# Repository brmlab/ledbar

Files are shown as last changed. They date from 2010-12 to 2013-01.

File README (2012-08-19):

eagle: PCB design
arduino: Semi-generic TLC59116 library and ledbar Arduino firmware
host: C frontend
host_python: Python frontend

Both the C frontend and the Python frontend have their pros and cons.
We still use both and it's unclear which one will prevail. Try them
and use the one you like better.

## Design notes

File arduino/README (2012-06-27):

autonomous.pde: This is autonomous LED controller that implements several
simple color cycling algorithms directly on Ardiuno - no host controller
is required. All LEDs have the same color. Useful for testing.

controlled.pde: Listens to a byte stream on serial. The byte stream should
contain one R,G,B tribyte per LED, sent repeatedly.

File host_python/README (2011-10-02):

INTRODUCTION:

The scripts in this directory try to work according to the KISS principle. It 
contains a script which redirects its stdin to serial device 
(send_to_serial.py), one that simulates the ledbar and sends the data unaltered 
from its stdin to its stdout, a module that helps programmers to program 
various graphical effects and some example effect generators using this module.

EXAMPLES:

./rainbow.py | ./demo.py >/dev/null
    - only simulate the rainbow effect, do not send it anywhere

./rainbow.py | ./send_to_serial.py
    - only send the data to the serial device, do not show the simulation

./rainbow.py | ./demo.py | ./send_to_serial.py
    - combine both options, show a simulation and send the data to the serial
      device

DEPENDENCIES:

demo.py requires PyGame, Python wrapper around SDL
send_to_serial.py requires PySerial, Python library for work with serial ports
equalizer.py requires PyAudio (wrapper around PortAudio) and a microphone

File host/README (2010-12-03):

* http://brmlab.cz/project/ledbar

* control with Q, W

* quit with escape or close the window

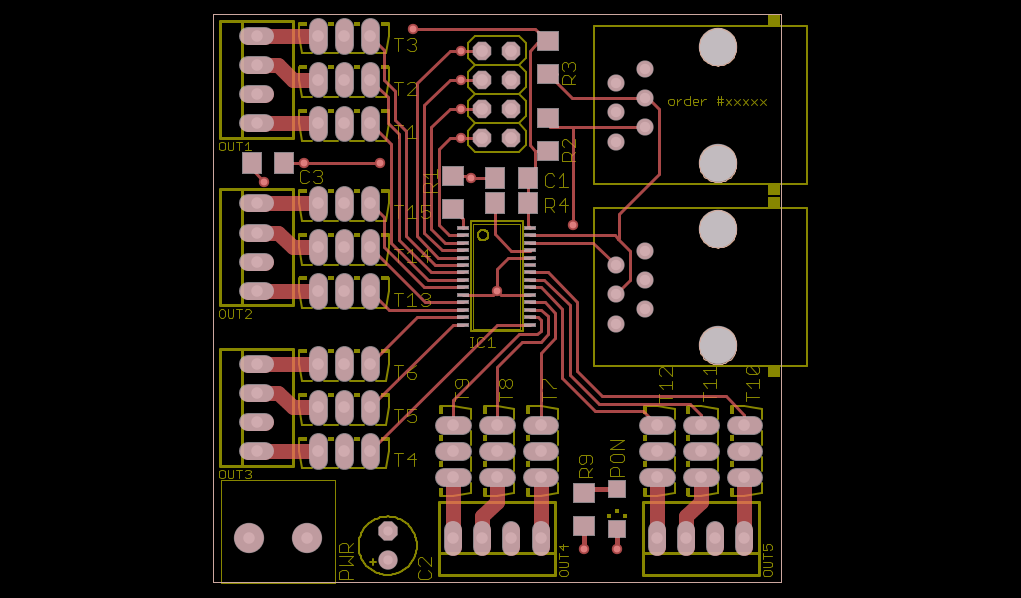
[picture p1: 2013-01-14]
eagle/ledbar/top.png

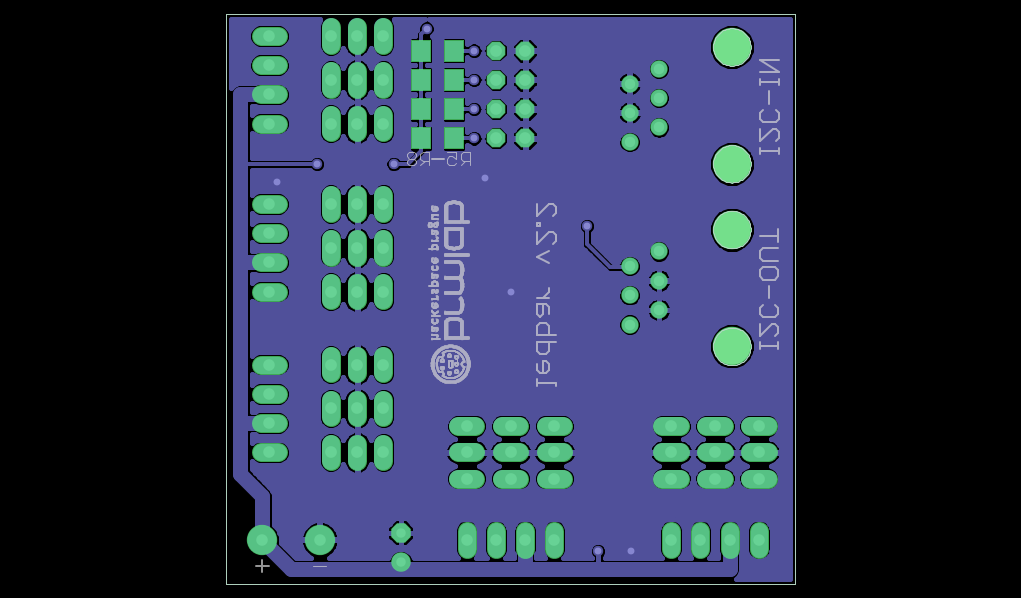
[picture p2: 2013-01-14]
eagle/ledbar/bottom.png

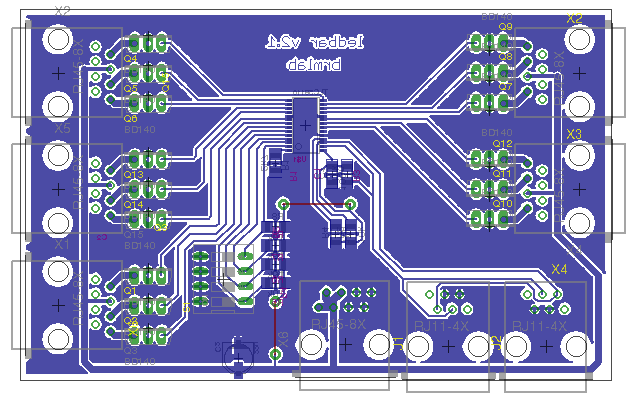
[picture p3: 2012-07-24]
eagle/ledbar/board_v2.1.png

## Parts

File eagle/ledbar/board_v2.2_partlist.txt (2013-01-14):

Partlist

Exported from board_v2.brd at 1/10/13 10:36 PM

EAGLE Version 6.3.0 Copyright (c) 1988-2012 CadSoft

Assembly variant: 

Part     Value          Package        Library             Position (mm)         Orientation

C1       100n           C1206          resistor            (26.035 35.2425)      R180
C2       22u            E2,5-5         resistor            (15.24 3.175)         R90
C3       1u             C1206          resistor            (4.7625 36.5125)      R180
I2C-IN   RJ11-4X        RJ11-NO_SHIELD con-tycoelectronics (44.0154 41.5925)     R90
I2C-OUT  RJ11-4X        RJ11-NO_SHIELD con-tycoelectronics (44.0154 25.7175)     R90
IC1      TLC59116       TSSOP28        tlc                 (24.765 26.67)        R270
JP1                     2X04           pinhead             (24.765 42.545)       R90
OUT1     22-23-2041     22-23-2041     con-molex           (3.81 43.815)         R90			http://cz.farnell.com/molex/22-23-2041/header-pin-4way/dp/1462920
OUT2     22-23-2041     22-23-2041     con-molex           (3.81 29.21)          R90
OUT3     22-23-2041     22-23-2041     con-molex           (3.81 15.24)          R90
OUT4     22-23-2041     22-23-2041     con-molex           (24.765 3.81)         R180
OUT5     22-23-2041     22-23-2041     con-molex           (42.545 3.81)         R180
PON                     CHIPLED_1206   led                 (35.2425 6.35)        R180
PWR      ARK210/2EX     ARK210/2EX     con-brm             (3.175 3.81)          R0
R1       2k7            R1206          resistor            (20.955 33.9725)      R270
R2       10k            R1206          resistor            (29.21 39.0525)       R270
R3       10k            R1206          resistor            (29.21 45.72)         R90
R4       4k7            R1206          resistor            (26.035 33.02)        R0
R5       10k            R1206          resistor            (18.415 46.355)       MR180
R6       10k            R1206          resistor            (18.415 43.815)       MR180
R7       10k            R1206          resistor            (18.415 41.275)       MR180
R8       10k            R1206          resistor            (18.415 38.735)       MR180
R9       220R           R1206          resistor            (32.385 6.35)         R90
T1       BD140          TO126AV        transistor-power    (11.43 41.275)        R0				http://cz.farnell.com/multicomp/bd140/transistor-pnp-to-126/dp/1574351	
T2       BD140          TO126AV        transistor-power    (11.43 45.085)        R0
T3       BD140          TO126AV        transistor-power    (11.43 48.895)        R0
T4       BD140          TO126AV        transistor-power    (11.43 12.7)          R0
T5       BD140          TO126AV        transistor-power    (11.43 16.51)         R0
T6       BD140          TO126AV        transistor-power    (11.43 20.32)         R0
T7       BD140          TO126AV        transistor-power    (27.305 11.43)        R90
T8       BD140          TO126AV        transistor-power    (23.495 11.43)        R90
T9       BD140          TO126AV        transistor-power    (19.685 11.43)        R90
T10      BD140          TO126AV        transistor-power    (45.085 11.43)        R90
T11      BD140          TO126AV        transistor-power    (41.275 11.43)        R90
T12      BD140          TO126AV        transistor-power    (37.465 11.43)        R90
T13      BD140          TO126AV        transistor-power    (11.43 26.67)         R0
T14      BD140          TO126AV        transistor-power    (11.43 30.48)         R0
T15      BD140          TO126AV        transistor-power    (11.43 34.29)         R0

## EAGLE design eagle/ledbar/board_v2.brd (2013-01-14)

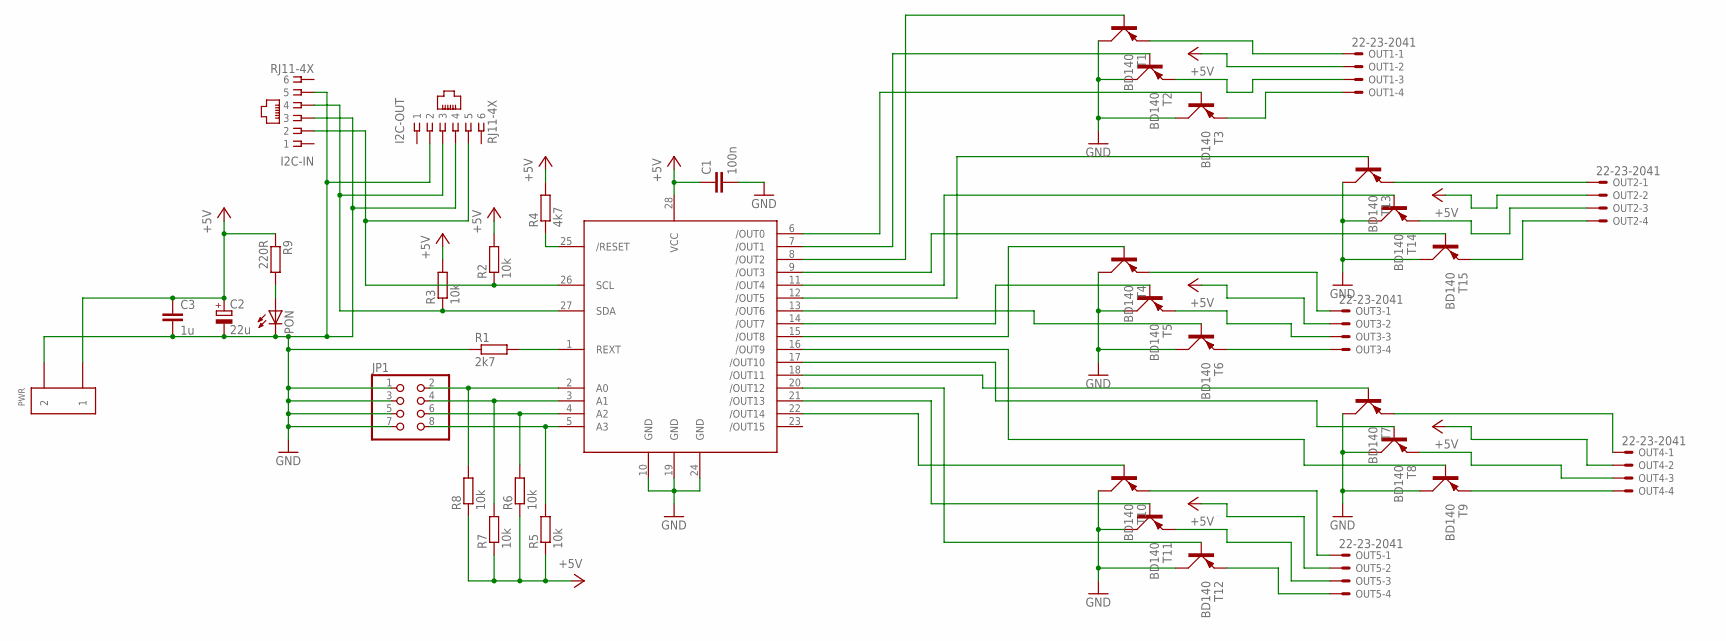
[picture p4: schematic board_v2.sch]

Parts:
C1: 100n; C1206
C2: 22u; E2,5-5
C3: 1u; C1206
I2C-IN: RJ11-4X; RJ11-NO_SHIELD
I2C-OUT: RJ11-4X; RJ11-NO_SHIELD; MPN 6609214-3
IC1: TLC59116; TSSOP28
JP1: PINHD-2X4; 2X04
OUT1, OUT2, OUT3, OUT4, OUT5: 22-23-2041
PON: LEDCHIPLED_1206; CHIPLED_1206
PWR: ARK210/2EX
R1: 2k7; R1206
R2, R3, R5, R6, R7, R8: 10k; R1206
R4: 4k7; R1206
R9: 220R; R1206
T1, T2, T3, T4, T5, T6, T7, T8, T9, T10, T11, T12, T13, T14, T15: BD140; TO126AV

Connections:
+5V: C1.1, C2.+, C3.1, IC1.28 (VCC), OUT1.2, OUT2.2, OUT3.2, OUT4.2, OUT5.2, PWR.P$1 (1), R2.2, R3.2, R4.2, R5.1, R6.1, R7.1, R8.1, R9.1
GND: C1.2, C2.-, C3.2, I2C-IN.3, I2C-IN.5, I2C-OUT.2, I2C-OUT.4, IC1.10 (GND), IC1.19 (GND), IC1.24 (GND), JP1.1, JP1.3, JP1.5, JP1.7, PON.C, PWR.P$2 (2), R1.1, T1.C, T2.C, T3.C, T4.C, T5.C, T6.C, T7.C, T8.C, T9.C, T10.C, T11.C, T12.C, T13.C, T14.C, T15.C
unnamed: OUT1.1, T1.E
unnamed: OUT1.3, T2.E
unnamed: OUT1.4, T3.E
unnamed: OUT3.1, T4.E
unnamed: OUT3.3, T5.E
unnamed: OUT3.4, T6.E
unnamed: OUT4.1, T7.E
unnamed: OUT4.3, T8.E
unnamed: OUT4.4, T9.E
unnamed: OUT5.1, T10.E
unnamed: OUT5.3, T11.E
unnamed: OUT5.4, T12.E
unnamed: OUT2.1, T13.E
unnamed: OUT2.3, T14.E
unnamed: OUT2.4, T15.E
unnamed: IC1.9 (/OUT3), T15.B
unnamed: IC1.2 (A0), JP1.2, R8.2
unnamed: IC1.3 (A1), JP1.4, R7.2
unnamed: IC1.4 (A2), JP1.6, R6.2
unnamed: IC1.5 (A3), JP1.8, R5.2
unnamed: IC1.1 (REXT), R1.2
unnamed: IC1.6 (/OUT0), T3.B
unnamed: IC1.7 (/OUT1), T2.B
unnamed: IC1.8 (/OUT2), T1.B
unnamed: IC1.11 (/OUT4), T14.B
unnamed: IC1.12 (/OUT5), T13.B
unnamed: IC1.13 (/OUT6), T6.B
unnamed: IC1.14 (/OUT7), T5.B
unnamed: IC1.15 (/OUT8), T4.B
unnamed: IC1.16 (/OUT9), T9.B
unnamed: IC1.17 (/OUT10), T8.B
unnamed: IC1.18 (/OUT11), T7.B
unnamed: IC1.20 (/OUT12), T12.B
unnamed: IC1.21 (/OUT13), T11.B
unnamed: IC1.22 (/OUT14), T10.B
unnamed: IC1.25 (/RESET), R4.1
unnamed: I2C-IN.2, I2C-OUT.5, IC1.26 (SCL), R2.1
unnamed: I2C-IN.4, I2C-OUT.3, IC1.27 (SDA), R3.1
unnamed: PON.A, R9.2

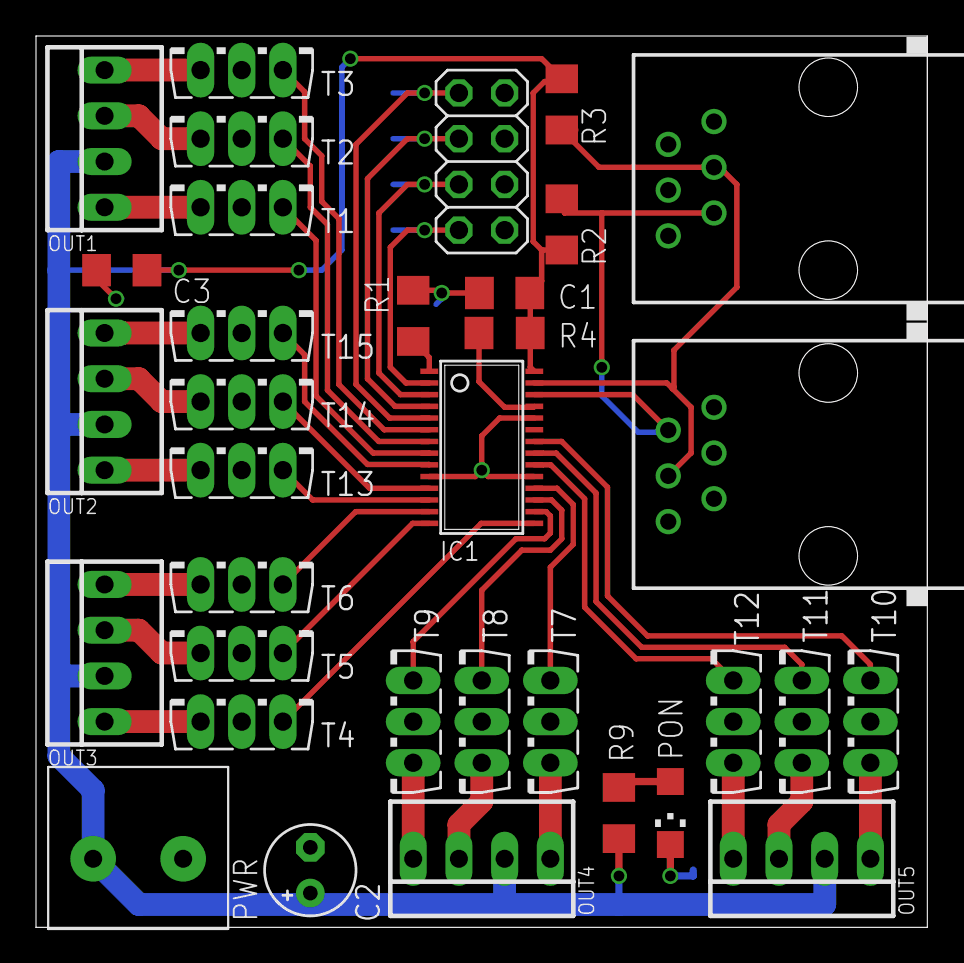
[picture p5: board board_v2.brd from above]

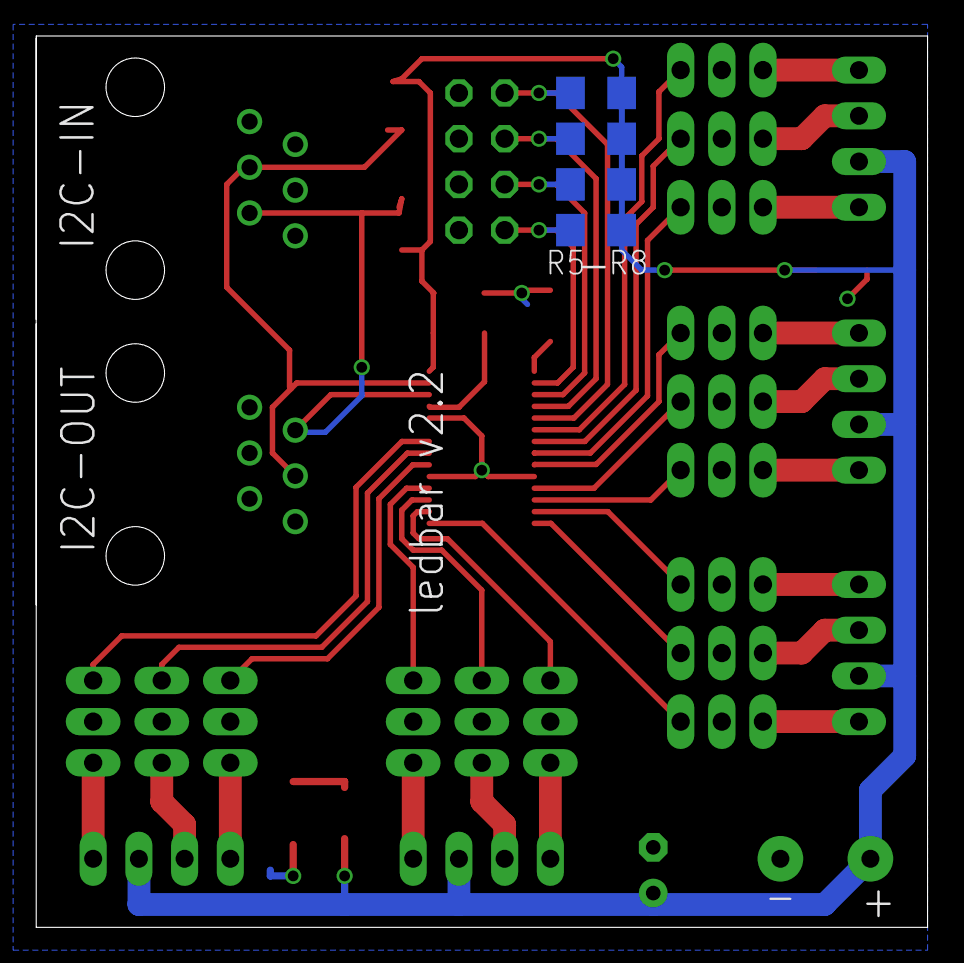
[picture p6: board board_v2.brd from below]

Board: 2 copper layers, 49.5 x 49.5 mm, 38 parts (4 on the bottom side), 41 nets.

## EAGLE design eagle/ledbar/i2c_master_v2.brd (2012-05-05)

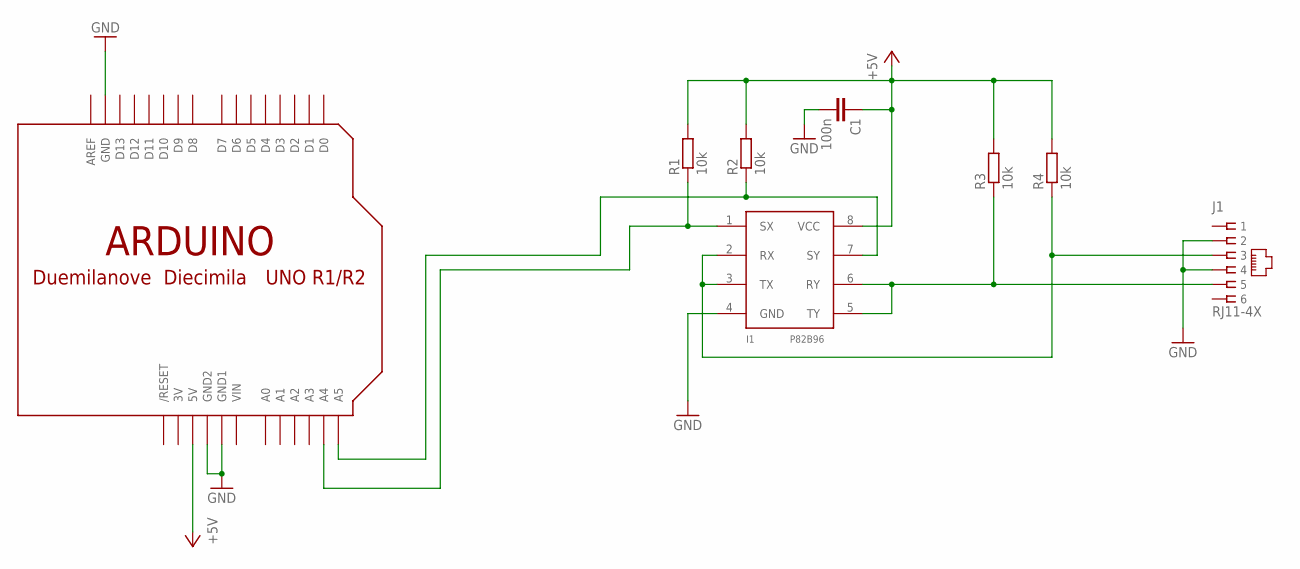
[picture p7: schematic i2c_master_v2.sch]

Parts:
C1: 100n; C1206
I1: P82B96; SOIC8
J1: RJ11-4X; RJ11-NO_SHIELD
R1, R2, R3, R4: 10k; M1206
U$1: ARDUINO-NOHOLE

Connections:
3V: U$1.3V
+5V: C1.1, I1.8 (VCC), R1.2, R2.2, R3.2, R4.2, U$1.5V
GND: C1.2, I1.4 (GND), J1.2, J1.4, U$1.GND, U$1.GND1, U$1.GND2
unnamed: I1.7 (SY), R2.1, U$1.A5
unnamed: I1.1 (SX), R1.1, U$1.A4
unnamed: I1.5 (TY), I1.6 (RY), J1.5, R3.1
unnamed: I1.2 (RX), I1.3 (TX), J1.3, R4.1
VIN: U$1.VIN

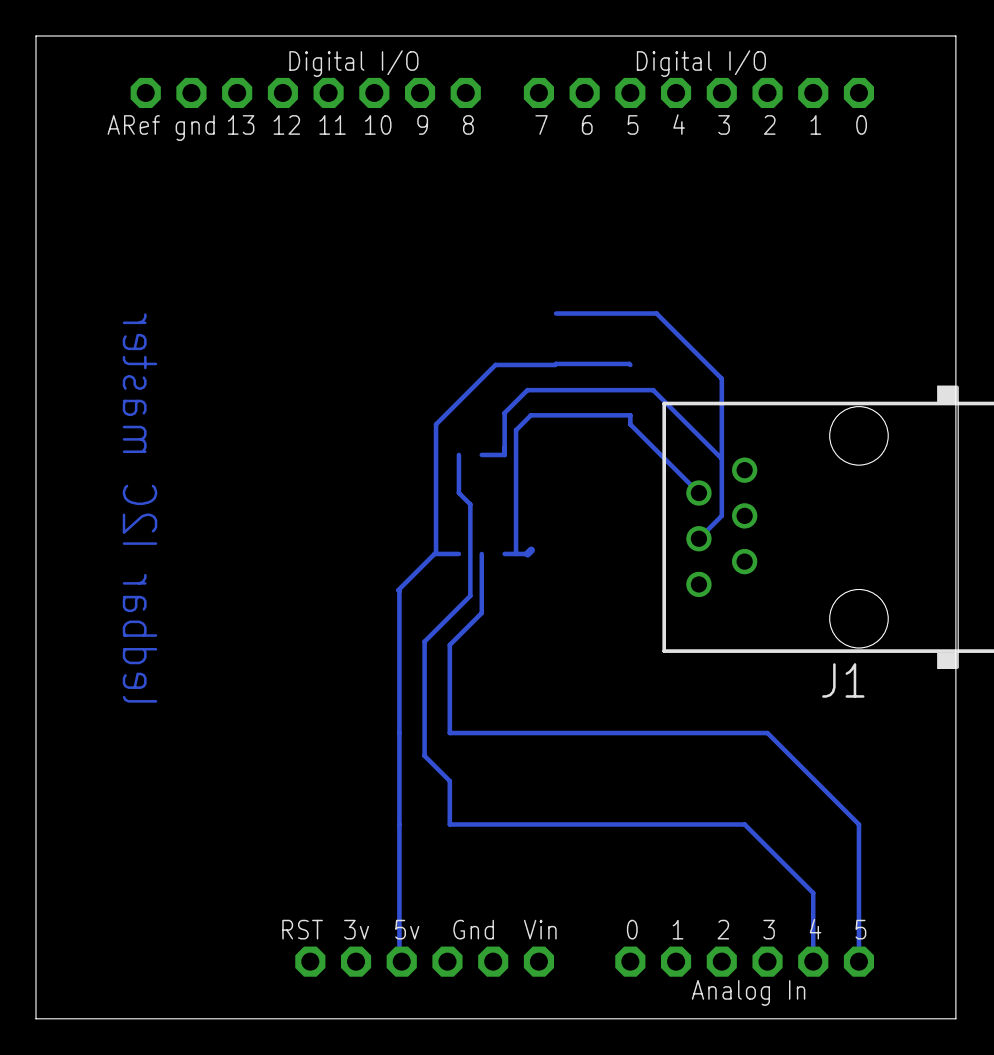
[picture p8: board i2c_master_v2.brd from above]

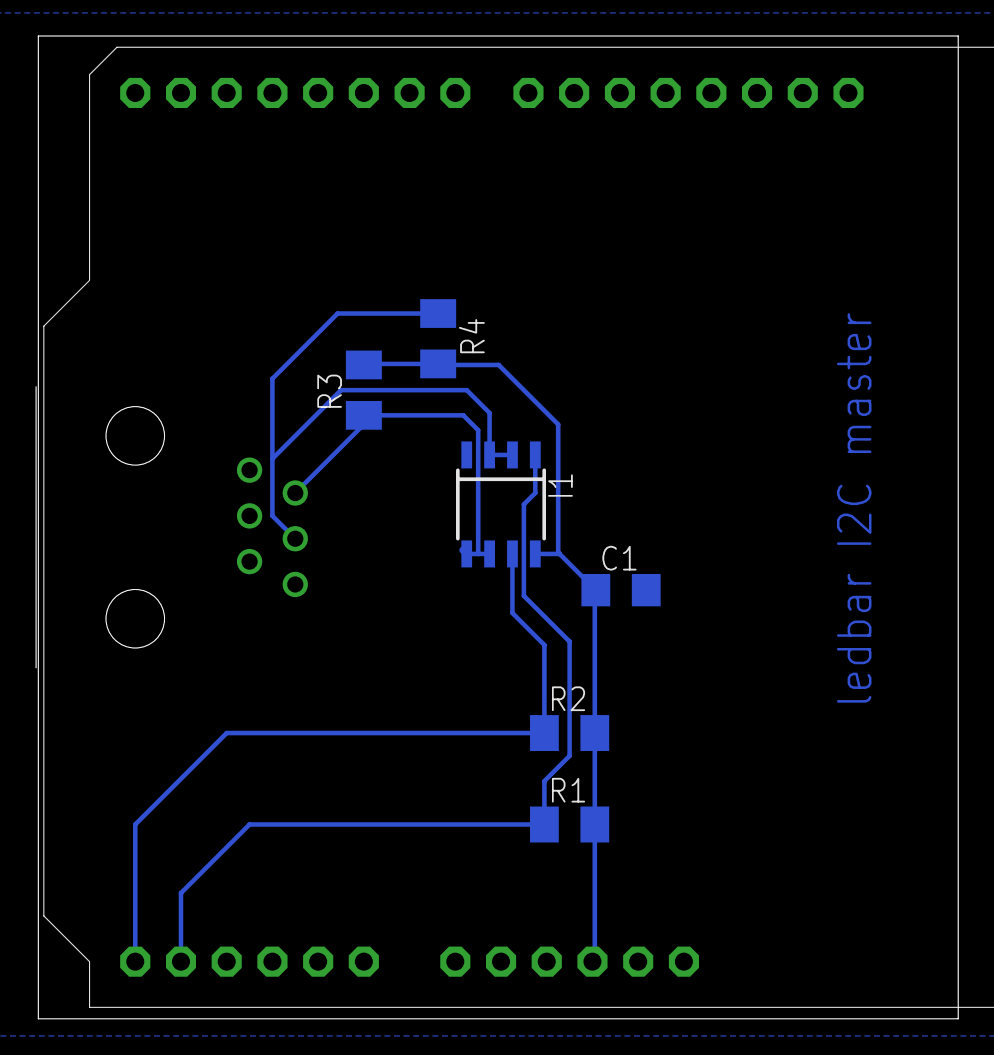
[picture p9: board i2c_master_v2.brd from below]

Board: 2 copper layers, 51.1 x 54.6 mm, 8 parts (6 on the bottom side), 6 nets.

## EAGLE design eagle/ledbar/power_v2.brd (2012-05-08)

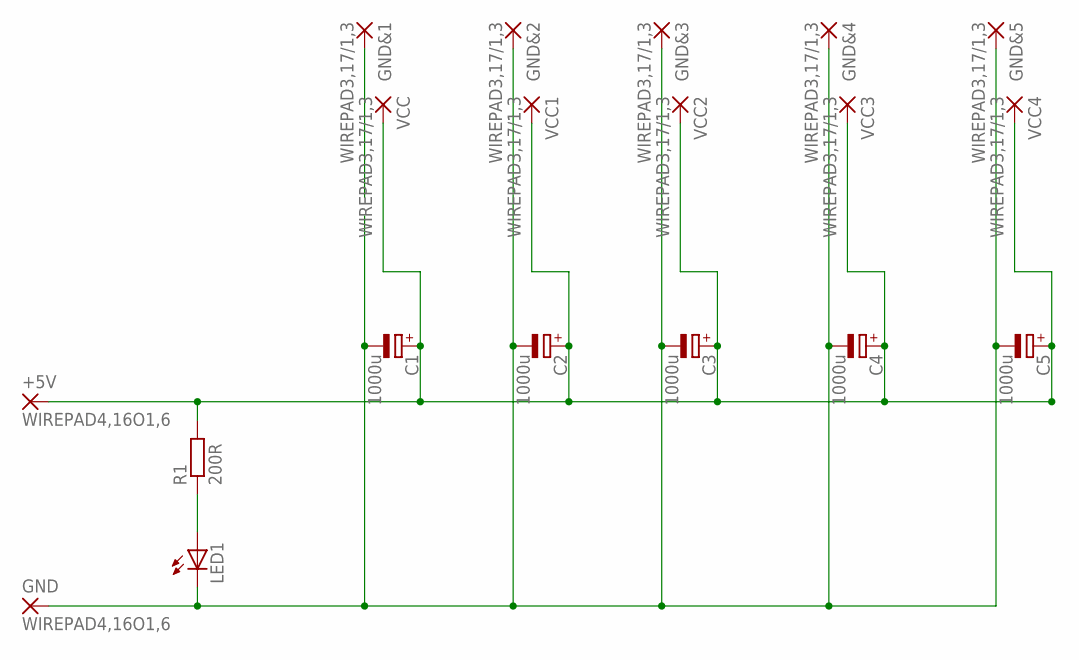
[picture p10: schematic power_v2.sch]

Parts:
+5V: WIREPAD4,16O1,6; 4,16O1,6
C1, C2, C3, C4, C5: 1000u; E5-10,5
GND: WIREPAD4,16O1,6; 4,16O1,6
GND&1, GND&2, GND&3, GND&4, GND&5: WIREPAD3,17/1,3; 3,17/1,3
LED1: LED5MM
R1: 200R; R1206
VCC, VCC1, VCC2, VCC3, VCC4: WIREPAD3,17/1,3; 3,17/1,3

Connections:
GND: C1.-, C2.-, C3.-, C4.-, C5.-, GND.1, GND&2.1, GND&3.1, GND&4.1, GND&5.1, LED1.K (C)
unnamed: LED1.A, R1.1
unnamed: +5V.1, C1.+, C2.+, C3.+, C4.+, C5.+, R1.2, VCC.1, VCC1.1, VCC2.1, VCC3.1, VCC4.1

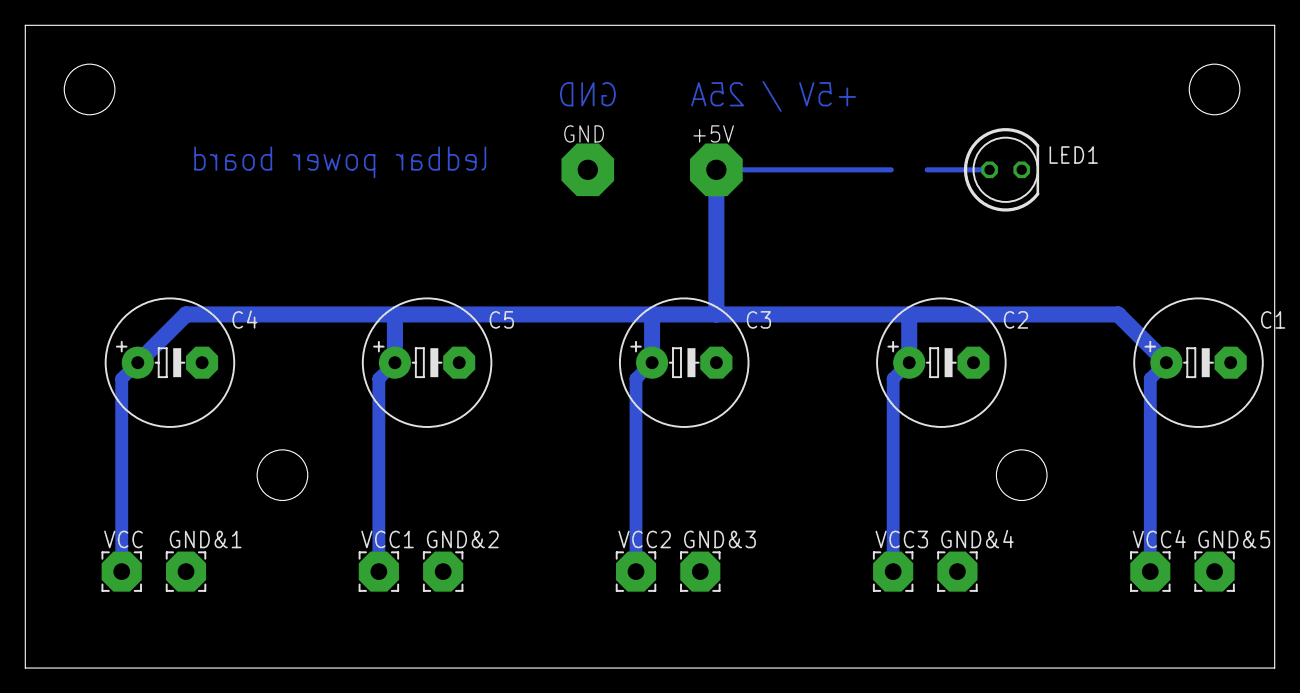
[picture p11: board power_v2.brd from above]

Board: 2 copper layers, 98.7 x 50.8 mm, 19 parts (1 on the bottom side), 3 nets.

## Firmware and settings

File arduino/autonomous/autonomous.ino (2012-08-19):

#include "../ledbar.h"

/* FIXME: cmin[] is not handled properly here, it's the level of 1, not 0. */

class Ledbar lb[NUM_TLCS];
int c[cpinsets][CH];

int wait = 10;

unsigned int xr1 = 19543;

void setup()
{
  Serial.begin(9600);
  int i = 0, led = 0;
  for (i = 0; i < NUM_TLCS; i++)
    lb[i].begin(B1100000 | i);
  for (led = 0; led < cpinsets; led++) {
    for (i = 0; i < CH; i++) {
      c[led][i] = map(5, 0, 10, cmin[led][i], cmax[led][i]);
      lb[cpin[led][i] >> 4].setPinMode(cpin[led][i] & 0xf, LPM_PWM);
    }
  }
  xr1 += analogRead(0);
}

int r(int ceiling)
{
  xr1 = 16807 * (xr1 & 0xfff) + (xr1 >> 12);
  return xr1 % ceiling;
}

/* One iteration of random colorspace walk. */
void random_walk(int led)
{
  static const int maxstep = 2;
  static const int maxbounce = maxstep * 2;
  static const int maxgrad = 16;
  static const int cmaxgrad[CH] = {maxgrad, maxgrad, maxgrad};
  static const int dampening = 8; // less means tend to smaller gradient
  static int g[cpinsets][CH];

  int i;

  for (i = 0; i < CH; i++) {
    g[led][i] += r(maxstep) * (r(2) ? 1 : -1);
    /* dampening */ g[led][i] += (g[led][i] > 0 ? -1 : 1) * r(abs(g[led][i])) / dampening;
    if (g[led][i] < -cmaxgrad[i]) g[led][i] = -cmaxgrad[i] + r(maxbounce); else if (g[led][i] > cmaxgrad[i]) g[led][i] = cmaxgrad[i] - r(maxbounce);

    c[led][i] += g[led][i];

    /* bounce */
    if (c[led][i] < cmin[led][i]) {
      c[led][i] = cmin[led][i];
      g[led][i] = -g[led][i] + r(maxbounce)-maxbounce/2;
    } else if (c[led][i] > cmax[led][i]) {
      c[led][i] = cmax[led][i];
      g[led][i] = -g[led][i] + r(maxbounce)-maxbounce/2;
    }
  }
}

void rainbow(int led)
{
  static int huephases[cpinsets];
  static int huephases_i[cpinsets];
#define HUEPHASE_LEN 512

  static int ini;
  if (!ini) {
    ini = 1;
    int v_max = 6 * HUEPHASE_LEN;
    for (int l = 0; l < cpinsets; l++) {
      int i = v_max * l / cpinsets;
      huephases[l] = i / HUEPHASE_LEN;
      huephases_i[l] = i % HUEPHASE_LEN;
    }
  }

  { int huephase = huephases[led], huephase_i = huephases_i[led];
  
#define huephase_to_c_inc(cc) map(huephase_i, 0, HUEPHASE_LEN, cmin[led][cc], cmax[led][cc])
#define huephase_to_c_dec(cc) map(HUEPHASE_LEN - huephase_i, 0, HUEPHASE_LEN, cmin[led][cc], cmax[led][cc])
  switch (huephase) {
    case 0: c[led][0] = cmax[led][0]; c[led][1] = huephase_to_c_inc(1); c[led][2] = cmin[led][2]; break;
    case 1: c[led][0] = huephase_to_c_dec(0); c[led][1] = cmax[led][1]; c[led][2] = cmin[led][2]; break;
    case 2: c[led][0] = cmin[led][0]; c[led][1] = cmax[led][1]; c[led][2] = huephase_to_c_inc(2); break;
    case 3: c[led][0] = cmin[led][0]; c[led][1] = huephase_to_c_dec(1); c[led][2] = cmax[led][2]; break;
    case 4: c[led][0] = huephase_to_c_inc(0); c[led][1] = cmin[led][1]; c[led][2] = cmax[led][2]; break;
    case 5: c[led][0] = cmax[led][0]; c[led][1] = cmin[led][1]; c[led][2] = huephase_to_c_dec(2); break;
  }
  
  huephase_i++;
  if (huephase_i > HUEPHASE_LEN) {
    huephase_i = 0;
    huephase = (huephase + 1) % 6;
  }
  
  huephases[led] = huephase; huephases_i[led] = huephase_i;
  }
}

/* One iteration of constant brightest white (useful for tuning constants for particular LEDs). */
void white(int led)
{
  int i;
  int mask = 1|2|4; // R, G, B
  for (i = 0; i < CH; i++) {
    c[led][i] = mask & (1 << i) ? map(255, 0, 255, cmin[led][i], cmax[led][i]) : 0;
  }
}


void custom(int led)
{
  int mled = cpinsets - 1 - led;
  int red   = map( led, 0, cpinsets - 1, 0, 100);
  int green = map(mled, 0, cpinsets - 1, 0, 100);;
  int blue  = 0;
  
  c[led][0] = map(red, 0, 100, cmin[led][0], cmax[led][0]);
  c[led][1] = map(green, 0, 100, cmin[led][1], cmax[led][1]);
  c[led][2] = map(blue, 0, 100, cmin[led][2], cmax[led][2]);
}


/* White "breathing" effect to a certain degree of intensity. Good for identifying a point where further intensity change does not make any difference. */
void grey(int led)
{
  static const int steps = 1000;
  static int s = 0;
  static int d = 1;

  int i;
  for (i = 0; i < CH; i++) {
    c[led][i] = map(s, 0, steps, cmin[led][i], cmax[led][i]);
  }
  if (s == steps) {
    d = -1;
  } else if (s == 0) {
    d = 1;
  }
  s += d;
}

void loop()
{
  int led;
  for (led = 0; led < cpinsets; led++) {
    //random_walk(led);
    rainbow(led);
    //white(led);
    //custom(led);
    //grey(led);
  }

  setbyc(lb, c);

  delay(wait);
}

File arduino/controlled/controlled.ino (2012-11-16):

#include "../ledbar.h"

class Ledbar lb[NUM_TLCS];
int c[cpinsets][CH];

int wait = 10;

void setup()
{
  Serial.begin(57600);
  int i = 0, led = 0;
  for (i = 0; i < NUM_TLCS; i++)
    lb[i].begin(B1100000 | i);
  for (led = 0; led < cpinsets; led++) {
    for (i = 0; i < CH; i++) {
      c[led][i] = cmax[led][i] / 2;
      lb[cpin[led][i] >> 4].setPinMode(cpin[led][i] & 0xf, LPM_PWM);
    }
  }
  Serial.println("- ready");
}

void loop()
{
  int led, i;
  /* Wait for synchronization. */
  do {
    while (!Serial.available());
  } while (Serial.read() != 0xAC);
  /* Set LEDs. */
  for (led = 0; led < cpinsets; led++) {
    for (i = 0; i < CH; i++) {
      while (!Serial.available());
      unsigned char s = Serial.read();
      //c[led][i] = s;
      c[led][i] = s == 0 ? 0 : map(s, 1, 255, cmin[led][i], cmax[led][i]);
      //Serial.print(c[led][i], DEC);
      //Serial.print(" ");
    }
  }
  setbyc(lb, c);
  //Serial.println(".");
}

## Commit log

2011-04-22 arduino/autonomous.pde: Add the autonomous LED control sketch
2011-09-20 Various changes to host/ledbar.c
2011-09-20 Current version of the autonomous sketch
2011-09-20 Flush fp after one complete frame
2011-09-20 Sleep at the beginning to give time for Arduino to settle
2011-09-20 Sketch for computer-controlled ledbar
2011-09-21 Added script which shows simulation of ledbar
    * depends on pygame, which is something like wrapper around SDL
    * it gets its input from stdin, displays it and sends it to stdout, so some other script can work with it further
2011-09-21 Added class simplifiing ledbar output
    * also added rainbow.py, which uses this class to create rainbow effect
2011-09-26 Fixed synchronization bugs in Python version
    [demo.py, send_to_serial.py]
2011-11-16 eagle files v2.1 - fixed clearance between pads and signal routes
    [ledbar.brd, ledbar.sch]
2011-11-17 ledbar-shield v2
    [ledbar-shield.brd, ledbar-shield.sch]
2011-11-17 more ledbar-shield fixes
    [ledbar-shield.brd, ledbar-shield.sch]
2011-11-17 ledbar board v2.2
    [ledbar.brd]
2011-11-17 ledbar howto poster
2012-05-05 New design of boards using TLC59116
    [board_v2.brd, board_v2.sch]
2012-05-05 power board v2
    [power_v2.brd, power_v2.sch]
2012-05-05 i2c master shield for arduino
    [i2c_master_v2.brd, i2c_master_v2.sch]
2012-05-05 i2c master shield for arduino - minor clearance fix
    [i2c_master_v2.brd]
2012-05-07 board chaining connectors
    [board_v2.brd, board_v2.sch]
2012-05-08 cinch -> svorkovnice
    [board_v2.brd, board_v2.sch, power_v2.brd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]
2012-05-15 moar changes
    [board_v2.brd, board_v2.sch]
2012-06-27 Convert arduino autonomous.pde to new TLC59116, single-TLC configuration
2012-06-28 i2c in crossover; removed jumper wires
    [board_v2.brd, board_v2.sch]
2012-06-30 arduino: Move ledbar configuration from autonomous to common ledbar.h
2012-06-30 arduino: Update controlled for new TLCs
2012-06-30 Arduino autonomous grey(): Lengthen breathing effect
2012-06-30 Arduino controlled: Fix ledbar addressing
    [controlled.ino]
2012-06-30 Arduino controlled: Wait for burst, then read whole led block
2012-06-30 Controlled: Switch to baudrate 115200
2012-06-30 arduino/ledbar.h: Limit to two boards for now
2012-07-20 Sketches Makefile: depend on ledbar.h
2012-07-20 Calibrate LED channels
2012-07-20 autonomous: Use new Ledbar::setAllPinPWM() method, much faster LED control
2012-07-20 autonomous: Bracket channels by cmin[] in addition to cmax[]; red channel requires some minimal trigger level
2012-07-20 autonomous: factor out setAllPinPWM() loop to ledbar.h:setbyc()
2012-07-20 Arduino controlled: Use setbyc(), cmin[]
2012-07-20 Arduino controlled: Get rid of debug prints, fix Serial.available() wait
    [controlled.ino]
2012-07-24 board v2.1
    * PCB size has been optimized
    * Layout has been redesigned to minimize current loop area.
    [board_v2.brd]
2012-07-24 board - increased via size
    [board_v2.brd]
2012-07-24 board - png image updated
2012-08-19 host_python: Change default number of LEDs to 20
2012-08-19 host: Also change default number of LEDs to 20
2012-08-19 arduino: Change firmware to use 20 LEDs instead of 10; we have 4 working TLC PCBs\!
2012-08-19 README: Add brief description of ledbar components
2012-08-19 arduino: Change cmin[] semantics - pwm level of channel level 1, not 0
    Should eliminate dim red light for black pixels.
2012-08-19 equalizer.py: In non-slow mode, spread values more in the [0,1] interval to account for low dynamic range of ledbar pixels
2012-08-21 board v2.2
    [board_v2.brd, board_v2.sch]
2012-08-21 board v2.2 - silkscreen cleanup
    [board_v2.brd, board_v2.sch]
2012-08-21 board v2.2 - gerber files for fusion pcb service, top & bottom pcb preview images
    [board_v2.GBL, board_v2.GBO, board_v2.GBS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]
2012-08-31 Board v2.2 - power-on LED added; minor adjustments to silkscreen (version, brmlab logo)
    [board_v2.brd, board_v2.sch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]
2012-09-14 equalizer: Fix loss of intensity in higher frequencies due to wider ranges
    [equalizer.py]
2012-09-14 equalizer: Reduce lag caused by averaging by giving less weight to older samples
2012-09-14 equalizer: Shorten CHUNK_SIZE, partially compensate with HISTORY_SIZE
    CHUNK_SIZE will make the FFT buckets bigger, causing better space usage
    by pixels; it will also reduce latency. with original HISTORY_SIZE,
    there is too much flicker.
    [equalizer.py]
2012-11-21 silkscreen update
    [board_v2.brd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]
2012-11-21 gerber files
2012-12-22 host_python/equalizer.py: Switch HUE default, add -H commandline option
2012-12-22 host_python/rainbow2d.py: Essential fixups; needs more work
    [rainbow2d.py]
2012-12-22 Update host_python/equalizer.py
    fix range of autocorrelation
    [equalizer.py]
2013-01-14 board v2.1 partlist
2013-01-14 board v2.2 partlist
2013-12-30 equalizer: Fix high CPU usage by waiting a tiny bit in case of no data fetched from soundcard
    [equalizer.py]
2014-06-23 Eagle files moved to eagle project
    [board_v2.brd, board_v2.sch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]
